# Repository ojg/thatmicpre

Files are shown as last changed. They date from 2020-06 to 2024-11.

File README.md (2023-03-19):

ThatMicPre
=====
A simple, high-quality DIY microphone pre-amplifier with switched gain.

The background for this project was that I needed a simple but good microphone preamp for doing acoustic measurements. I needed a switched gain to be able to reproduce the gain setting in a more predictable way than what is possible with a potmeter. I could not find any existing DIY designs, so I decided to make one.

The design is based on the excellent [THAT1510 or THAT1512](https://thatcorp.com/that-1510-1512-low-noise-high-performance-audio-preamplifiers/) preamp ICs. It is also compatible with [SSM2019](https://www.analog.com/en/products/ssm2019.html) or [INA217](https://www.ti.com/product/INA217). I have followed all THAT's datasheets and app-notes to implement a robust, best-practice design.

A goal was to use simple through-hole parts that I and other DIYers usually have in our parts drawer. So there are no additional IC's or voltage regulators for example, it just uses simple transistors, capacitors and zener diodes for supply filtering and regulation. I selected affordable switches and connectors to keep cost down. Many parts can be substituted without sacrificing performance.

There are two versions of this design, one suited for a desktop encolsure with gain switch on top, and one suited for a rack-mount enclosure with gain switch on the front.

There is a separate PCB project in the panels folder that contains PCB layout for front and back panels that fits the 1455K120x case. Since it is copper-clad on the inside, it makes for a nice shielded box.

This is an open-source project released under CC-BY-SA-4.0 license. It basically means you can use it as you want as long as you share modifications under the same license, and attribute back to this project. See [LICENSE.txt](../blob/master/LICENSE.txt) for details.

See discussion of this project in this [DIYAudio thread.](https://www.diyaudio.com/forums/equipment-and-tools/356317-thatmicpre-source-mic-preamp.html) If you decide to build this pre-amplifier, please post results of your build there.

Specifications
-----
* Microphone preamplifier with switched gain and 48V phantom power.
* XLR input and output connectors.
* Phantom power on/off switch.
* Phase invert switch.
* Gains (dB): 0, 10, 15, 20, 25, 30, 35, 40, 45, 50, 55, 60.
* Gain deviation from nominal: Max +/-0.5dB using R12-series resistors.
* Frequency response: 0/-3dB from 10Hz to 100kHz for all gain settings.
* Input impedance: 2.0kohm differential (1kHz)
* Impedance balanced output, output impedance 200ohm (1kHz)
* Max output level: 20dBu at 0.1% THD (1kHz).
* THD+N less than 0.005% at 1kHz at 18dBu output level for all gain settings (20-20kHz BW).
* 48V DC power supply required, 30mA max. 
  * (Will operate with lower voltage DC power supplies with reduced phantom voltage and max output level).
* PCB dimensions 75mm x 120mm, fits the [Hammond 1455K120x](https://www.hammfg.com/part/1455K1201) enclosure.
  * Desktop version has gain switch on top of enclosure for easy access.
  * Rack version has gain switch on front for easy mounting in a rack enclosure.

Photos
-----
#### Desktop version
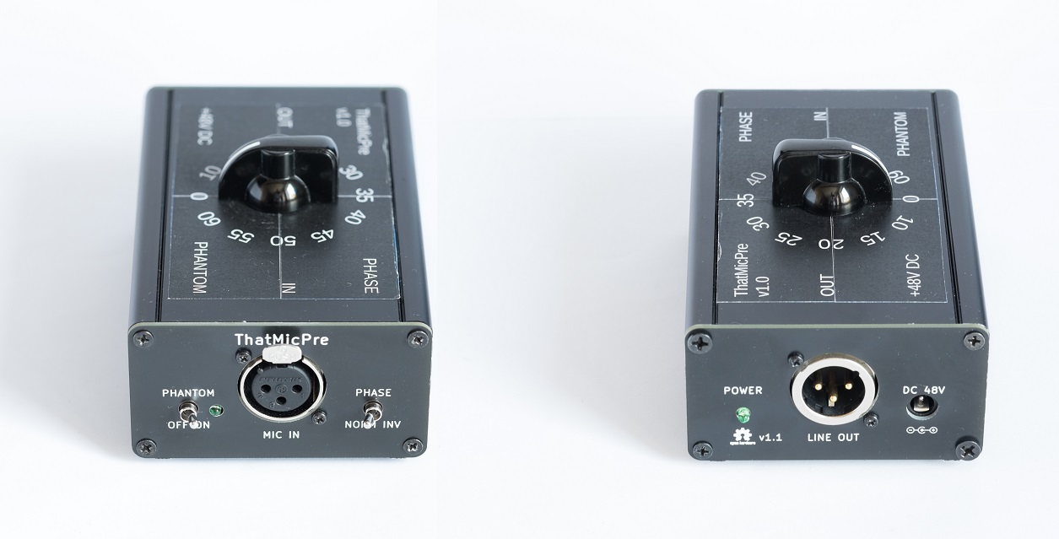
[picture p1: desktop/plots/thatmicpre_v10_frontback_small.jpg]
Photo of desktop Desktop with panels


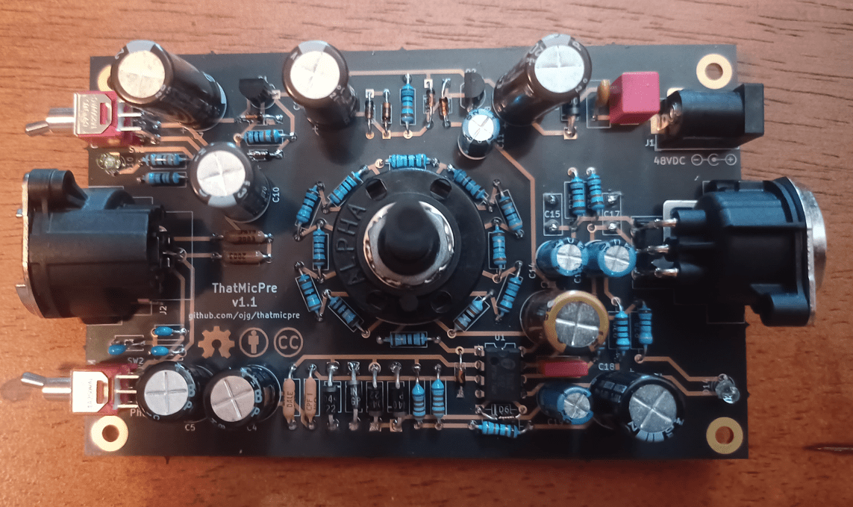
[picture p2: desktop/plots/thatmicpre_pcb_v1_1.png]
Photo of desktop pcb Desktop PCB photo

(PCBA credit jsenderatx on diyaudio)

#### Rack version
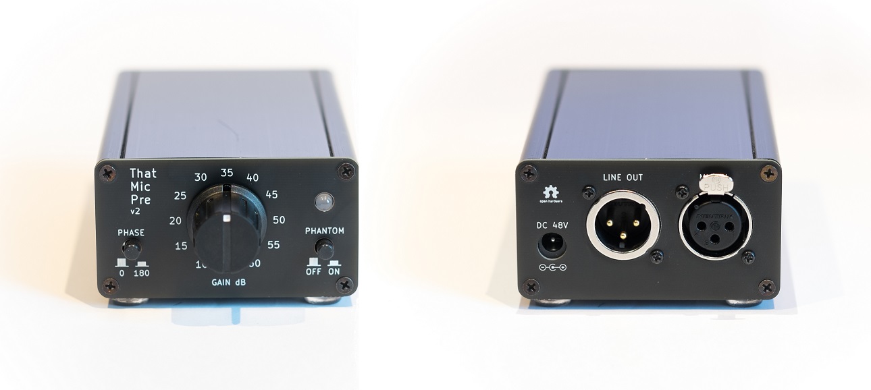
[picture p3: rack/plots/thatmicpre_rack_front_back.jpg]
Photo of rack Rack with panels


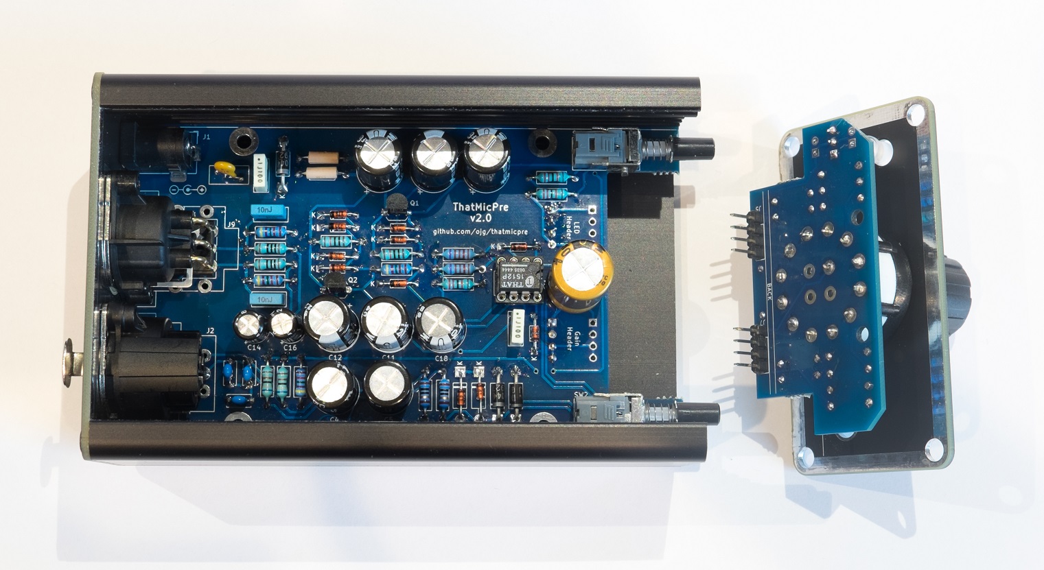
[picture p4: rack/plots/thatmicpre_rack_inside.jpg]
Photo of rack pcb Rack PCB photo


The rack version has a PCB where one part separates. This part contains the gain resistors and switch.
It mounts at a right angle to the main PCB with two angled female headers underneath main PCB. See BOM.

## Bill of Materials
Nicely formatted BOM is in the plots folder for [desktop version](https://htmlpreview.github.io/?https://github.com/ojg/thatmicpre/blob/master/desktop/plots/thatmicpre_bom.html)
and [rack version](https://htmlpreview.github.io/?https://github.com/ojg/thatmicpre/blob/master/rack/plots/thatmicpre_v2_bom.html).

Thanks to the [InteractiveHtmlBom project](https://github.com/openscopeproject/InteractiveHtmlBom).

Schematic
-----
#### Desktop version
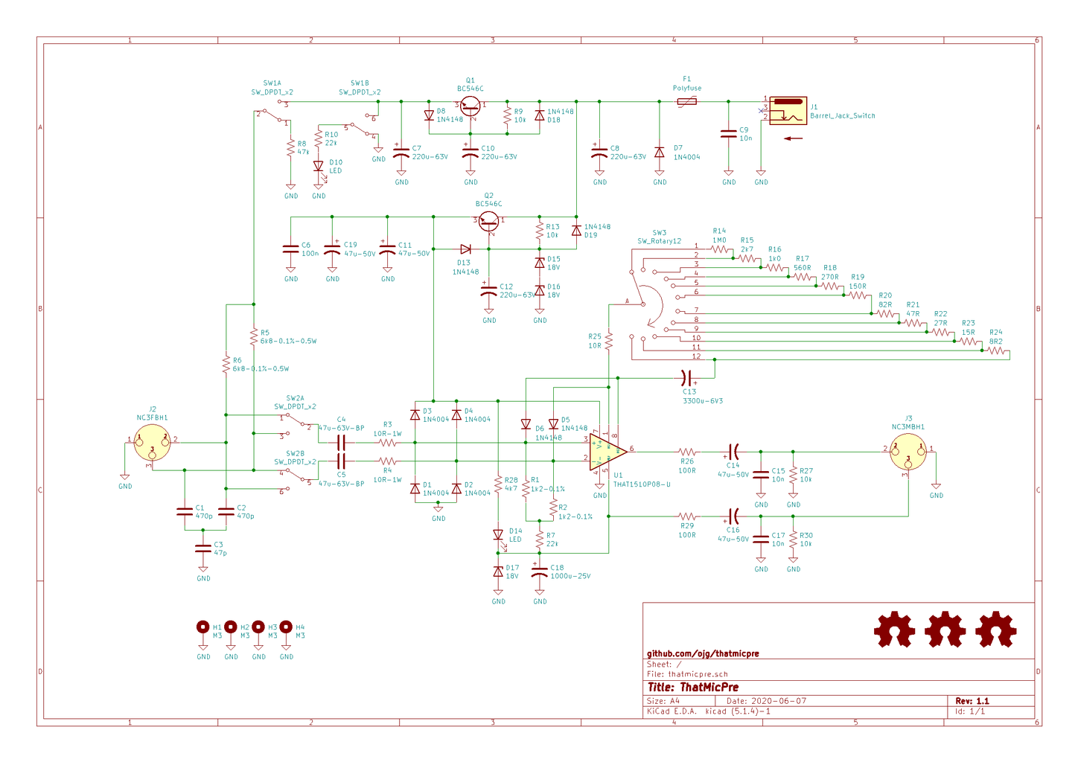
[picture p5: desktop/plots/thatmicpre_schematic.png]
Schematic

#### Rack version
Schematic

Measurements
-----
### Output noise vs gain
20-22kHz BW un-wtd, 150ohm source impedance.
Note: Theoretical minimum EIN with 150ohm source impedance is -130.4dBu.

| Gain(dB) | THAT1510<br />Output Noise (dBu) | THAT1510<br />EIN (dBu) | THAT1512<br />Output Noise (dBu) | THAT1512<br />EIN (dBu) |
| --- | --- | --- |--- | --- |
| 0 | -98.5 | -98.5 | -102.4 | -102.4 |
| 10 | -98.2 | -108.2 | -102.0 | -112.0 |
| 15 | -97.8 | -112.8 | -101.3 | -116.3 |
| 20 | -96.8 | -116.8 | -100.0 | -120.0 |
| 25 | -95.6 | -120.6 | -98.0 | -123.0 |
| 30 | -93.2 | -123.2 | -95.2 | -125.2 |
| 35 | -89.8 | -124.8 | -91.5 | -126.5 |
| 40 | -86.8 | -126.8 | -87.3 | -127.3 |
| 45 | -82.6 | -127.6 | -82.8 | -127.8 |
| 50 | -77.8 | -127.8 | -78.1 | -128.1 |
| 55 | -73.1 | -128.1 | -73.3 | -128.3 |
| 60 | -68.3 | -128.3 | -68.6 | -128.6 |

### Frequency Response
#### THAT1510 with 1% R12 resistors
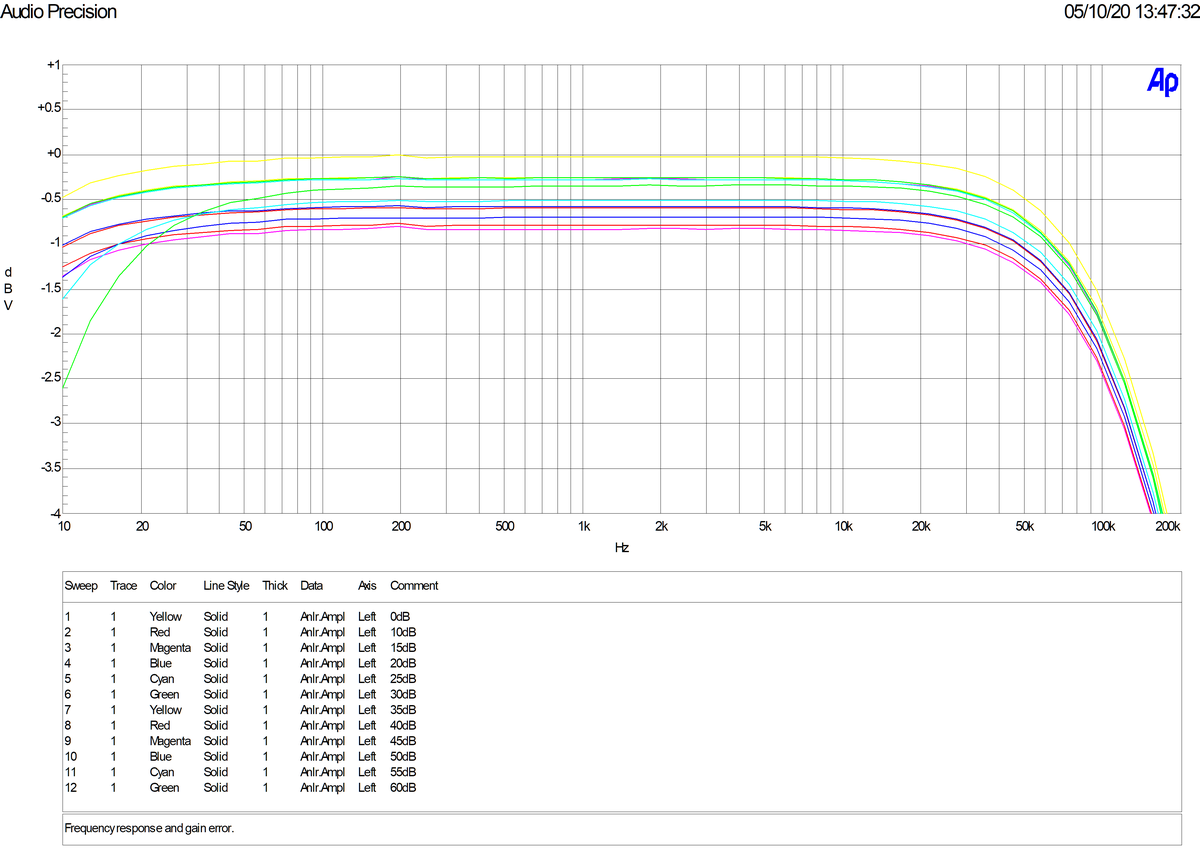
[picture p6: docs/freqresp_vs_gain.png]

#### THAT1512 with 1% R96 resistors
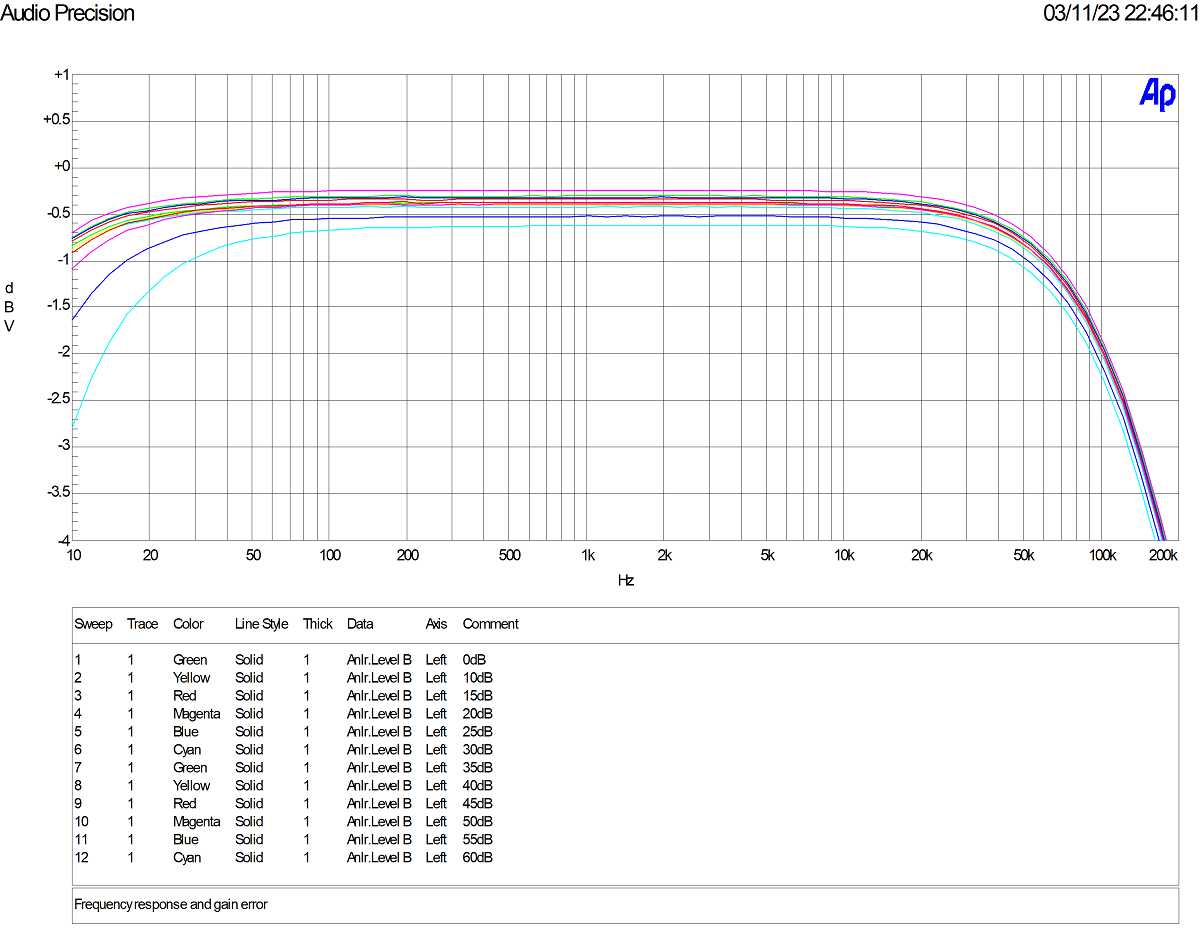
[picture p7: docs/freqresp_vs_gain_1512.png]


### THD+N vs Frequency
#### THAT1510
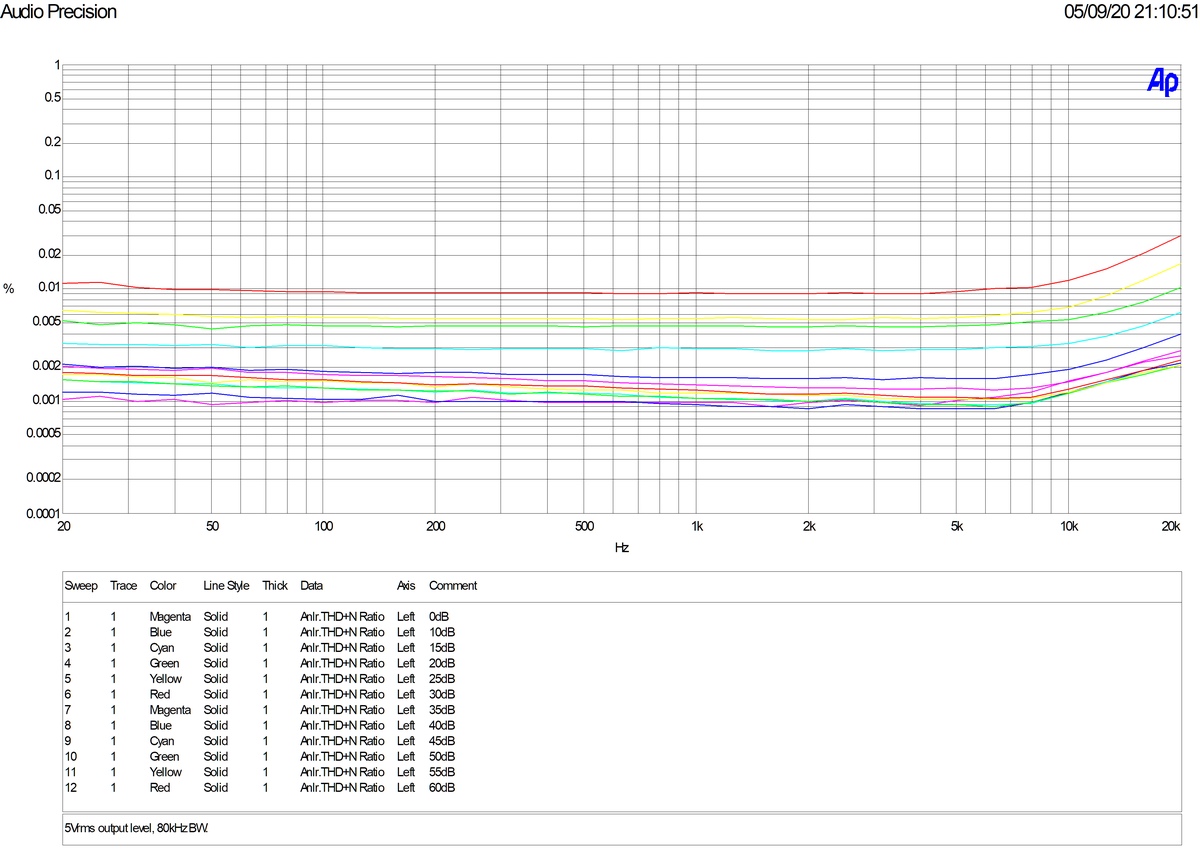
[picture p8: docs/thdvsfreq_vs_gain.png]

#### THAT1512
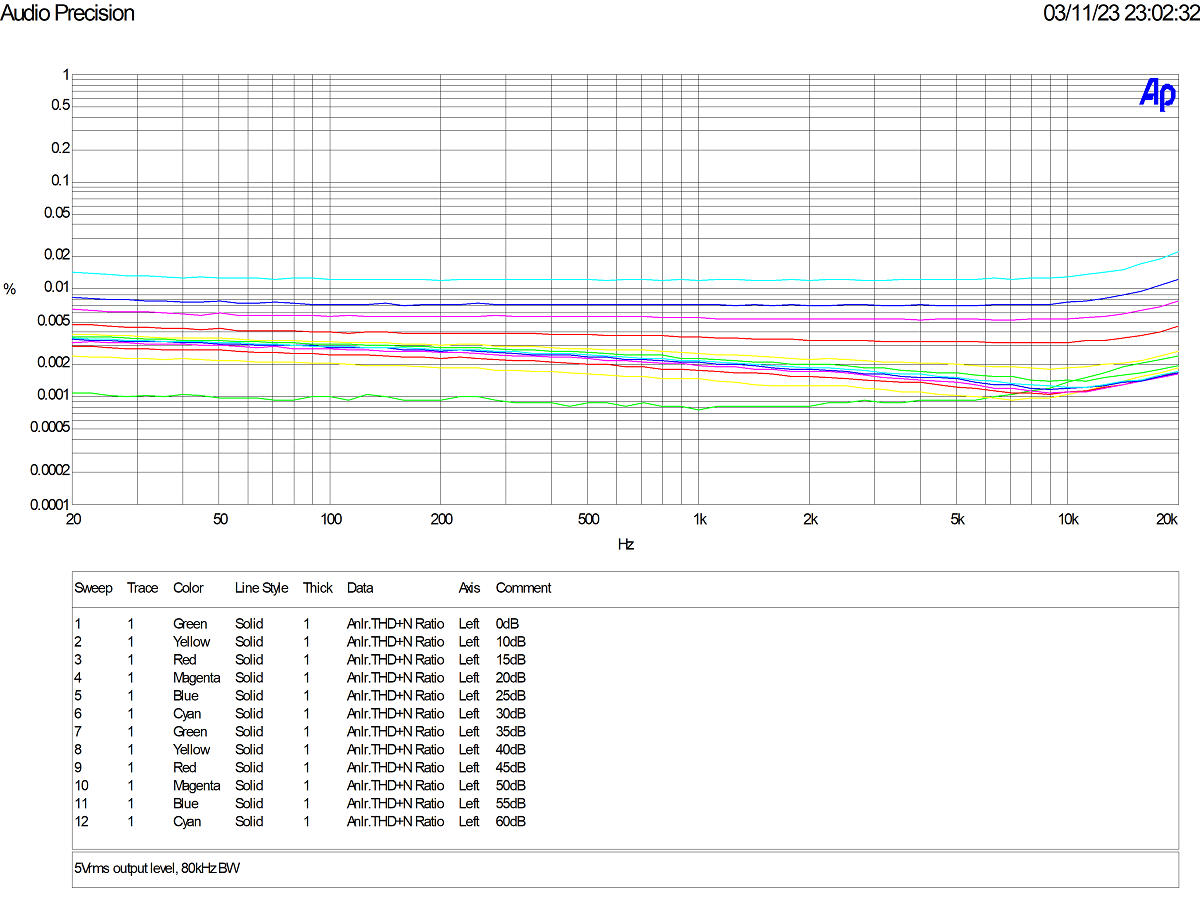
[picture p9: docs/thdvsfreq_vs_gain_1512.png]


### THD+N vs Amplitude
#### THAT1510
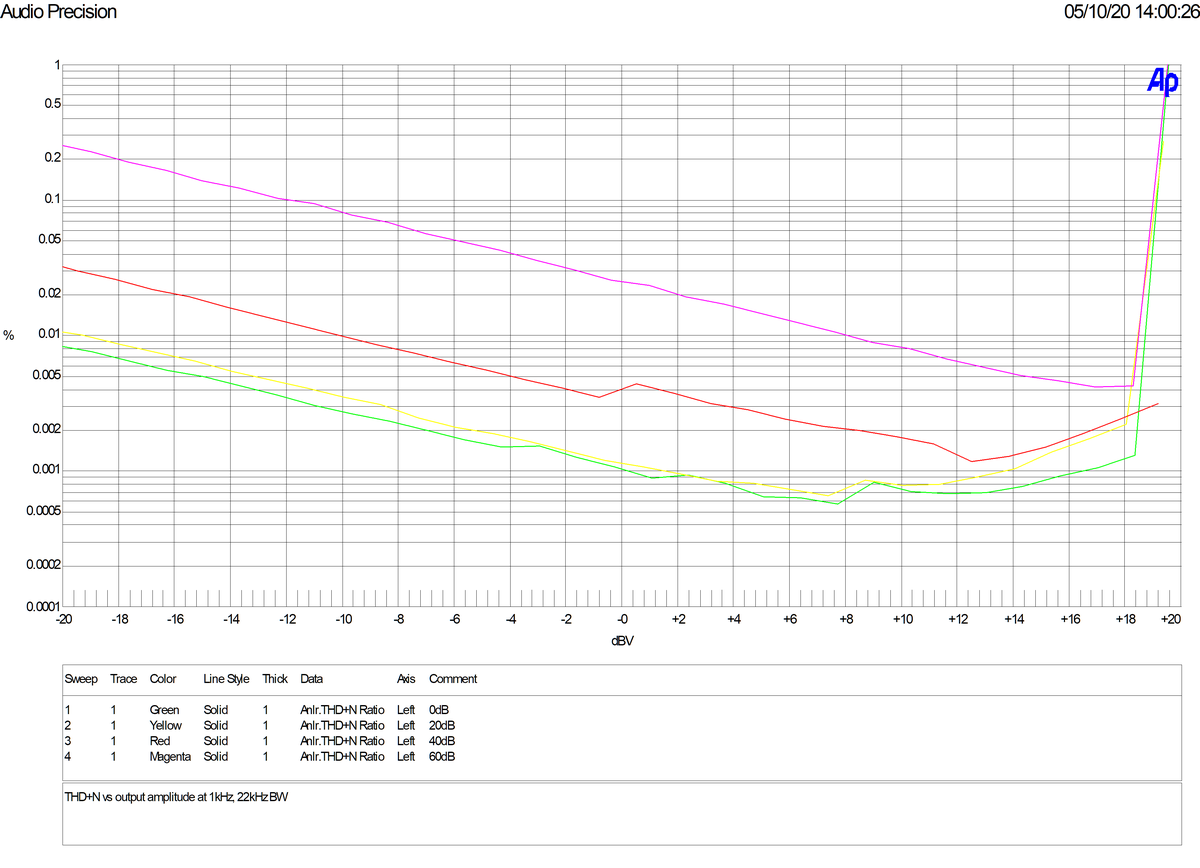
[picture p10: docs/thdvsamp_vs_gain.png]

#### THAT1512
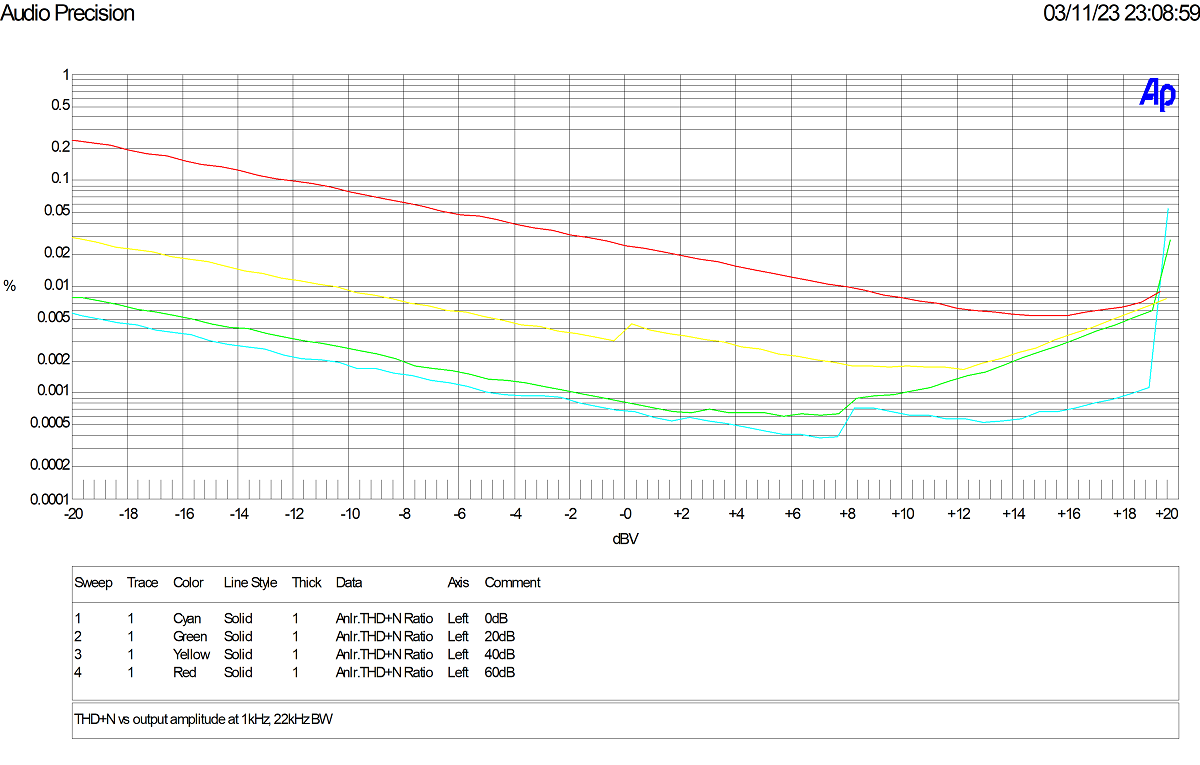
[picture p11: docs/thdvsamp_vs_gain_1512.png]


### Common Mode Rejection Ratio
#### THAT1510
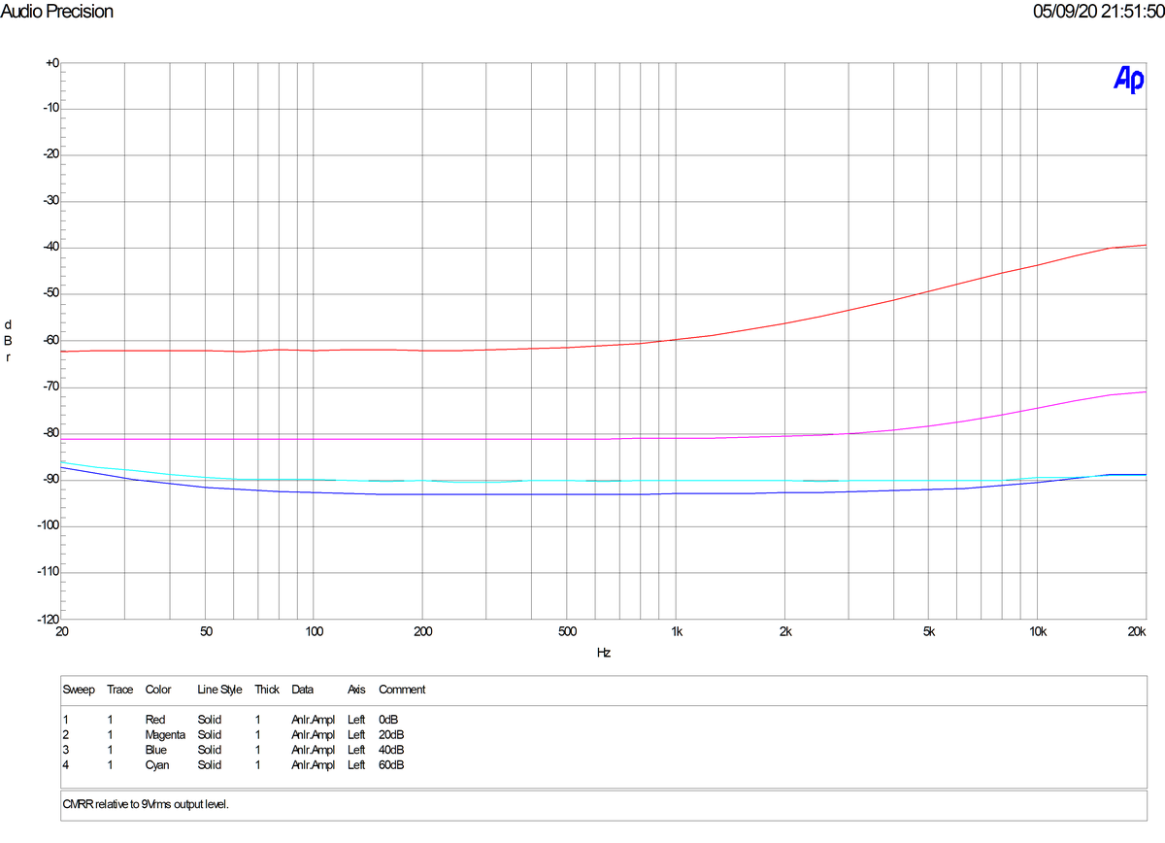
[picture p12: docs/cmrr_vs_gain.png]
CMRR

#### THAT1512
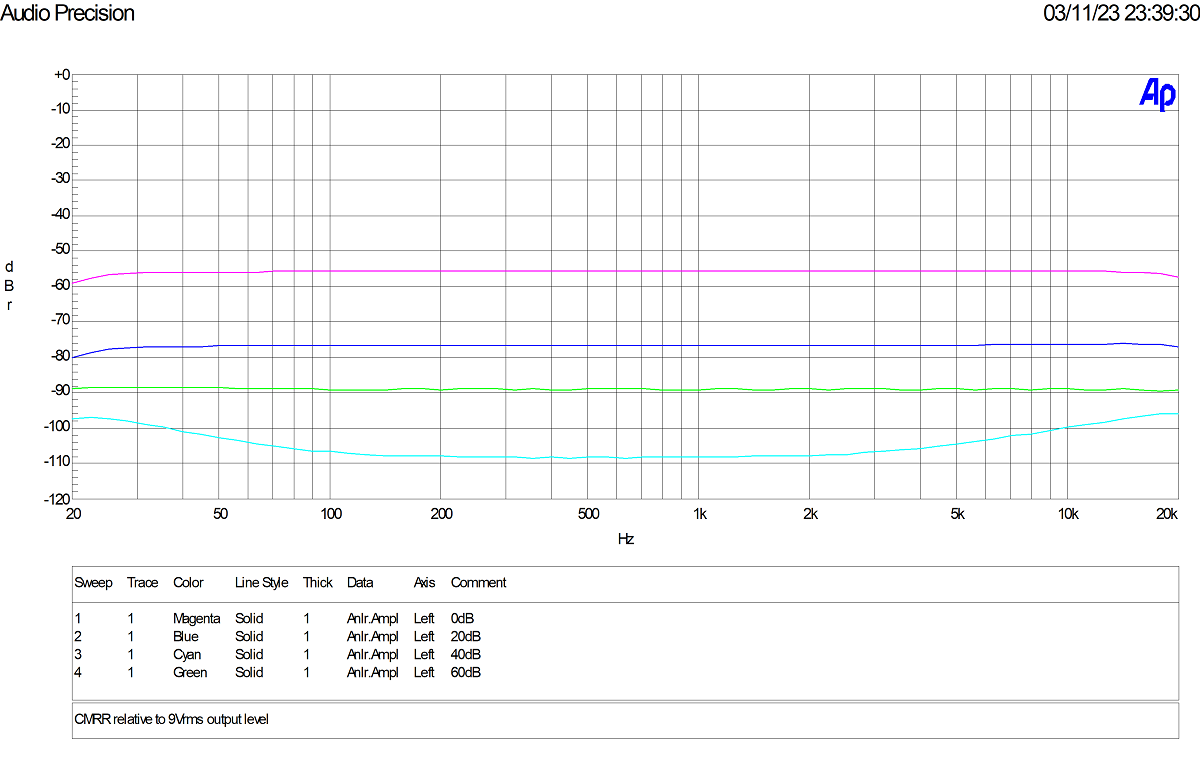
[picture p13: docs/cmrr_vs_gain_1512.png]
CMRR


### Bandpass Noise Level
Note no measureable hum.
#### THAT1510
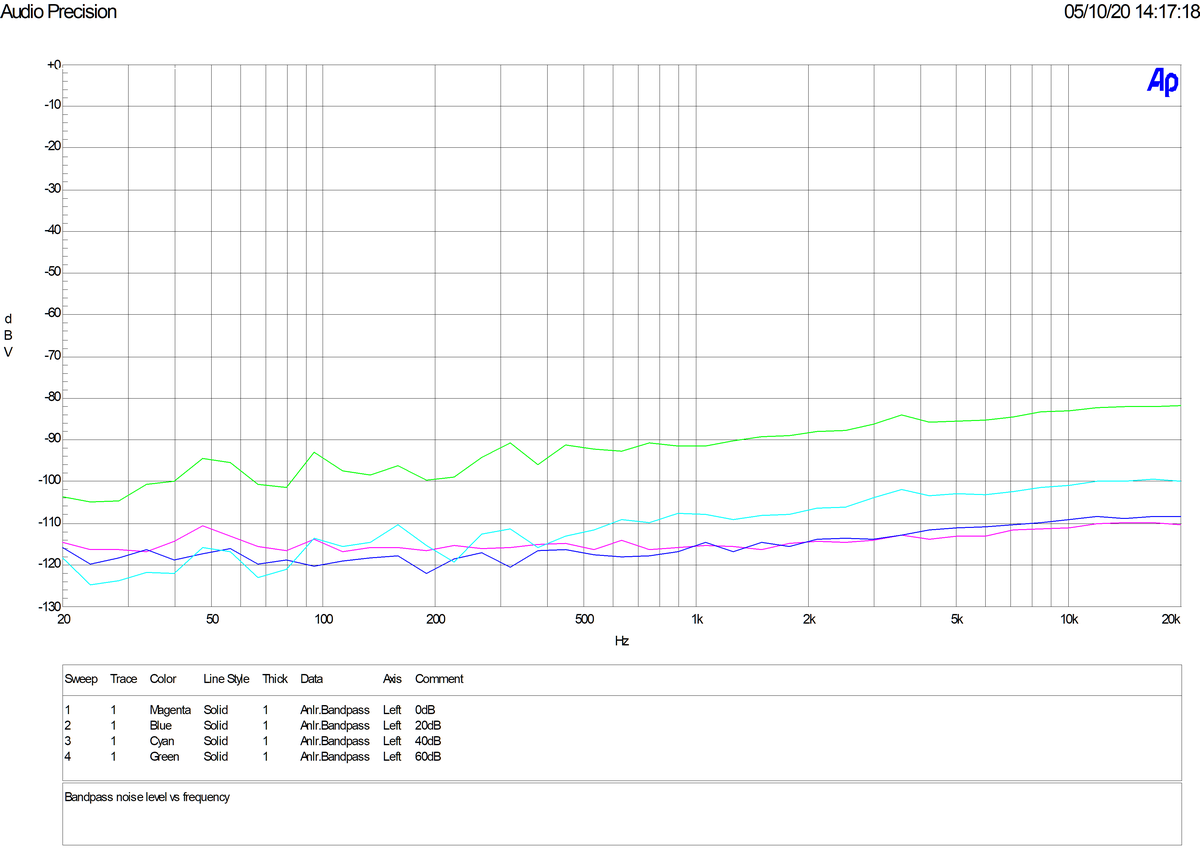
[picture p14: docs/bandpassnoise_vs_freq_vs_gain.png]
Bandpass

#### THAT1512
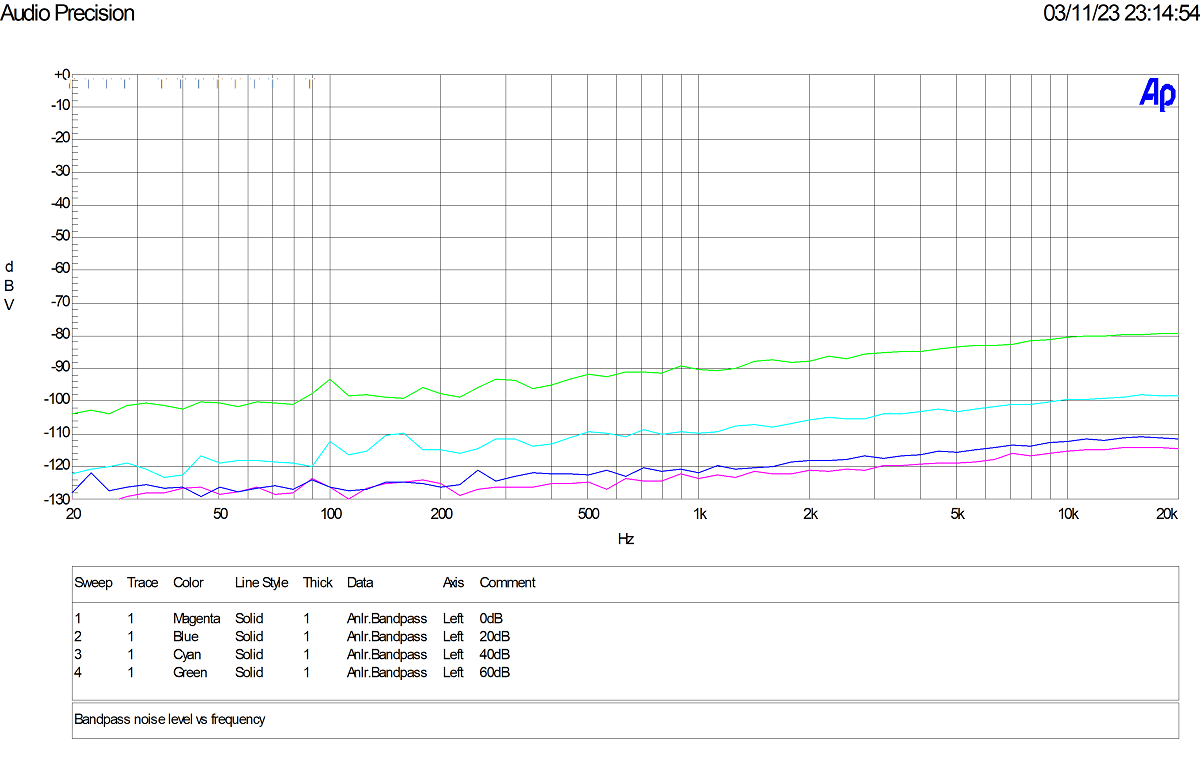
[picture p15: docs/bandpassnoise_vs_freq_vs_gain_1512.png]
Bandpass


---
OJG 2023

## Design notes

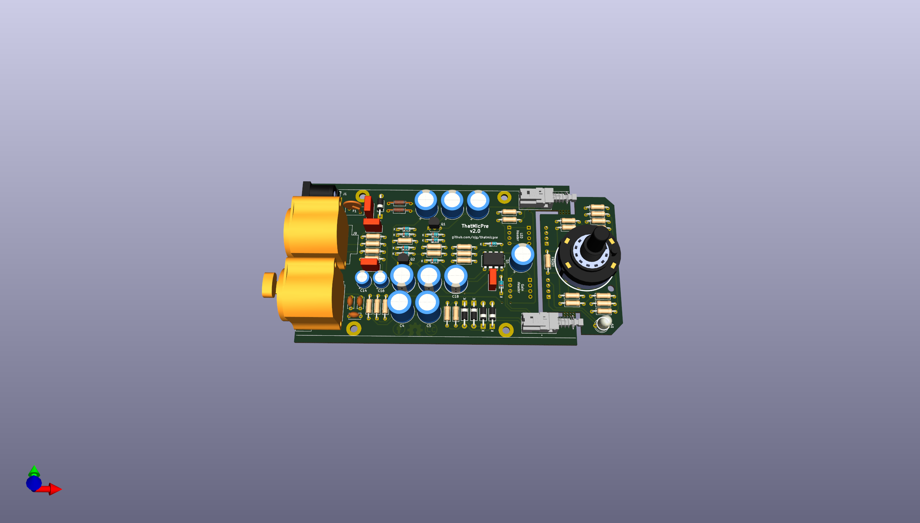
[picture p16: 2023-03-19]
rack/plots/thatmicpre_v2_3drender.png

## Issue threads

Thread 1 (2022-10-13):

input impedance problem

SJetandKara, 2022-10-13:
what is the input impedance of this preamp？
maybe by tweaking the input impedance we can get different sound features like ISA preamp(which provided input impedance options like 600Ω/1100Ω/2.4kΩ/6.8kΩ)？

ojg, 2022-10-16:
The input impedance with the values shown in the schematic is ~2kohm differentially.

It's (R5+R6) || (R1+R2). So you can tune it easily by changing R1 and R2.

Closed 2024-02-11.

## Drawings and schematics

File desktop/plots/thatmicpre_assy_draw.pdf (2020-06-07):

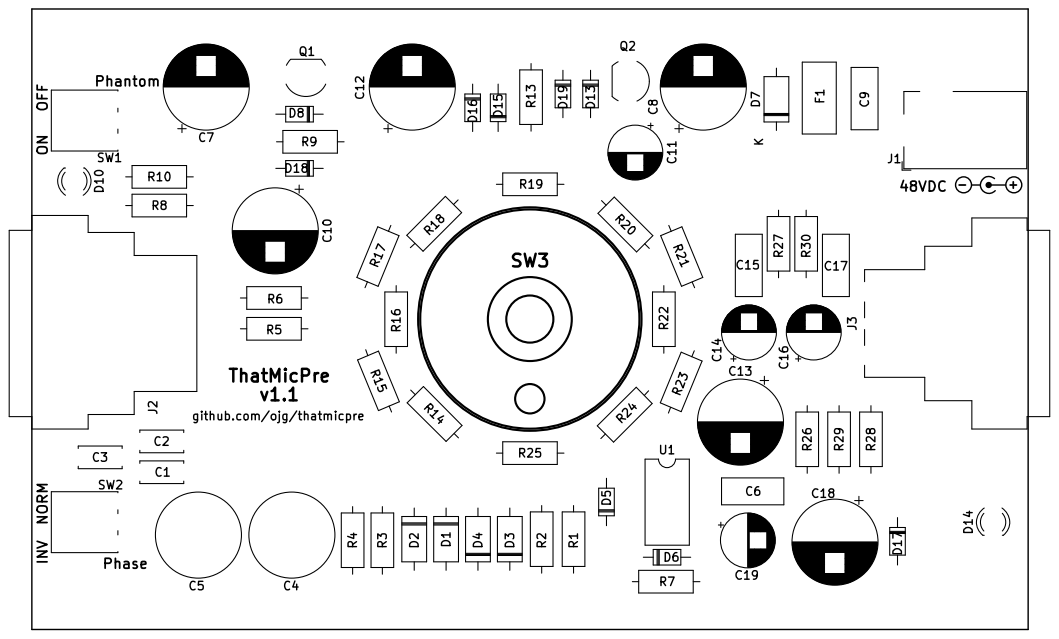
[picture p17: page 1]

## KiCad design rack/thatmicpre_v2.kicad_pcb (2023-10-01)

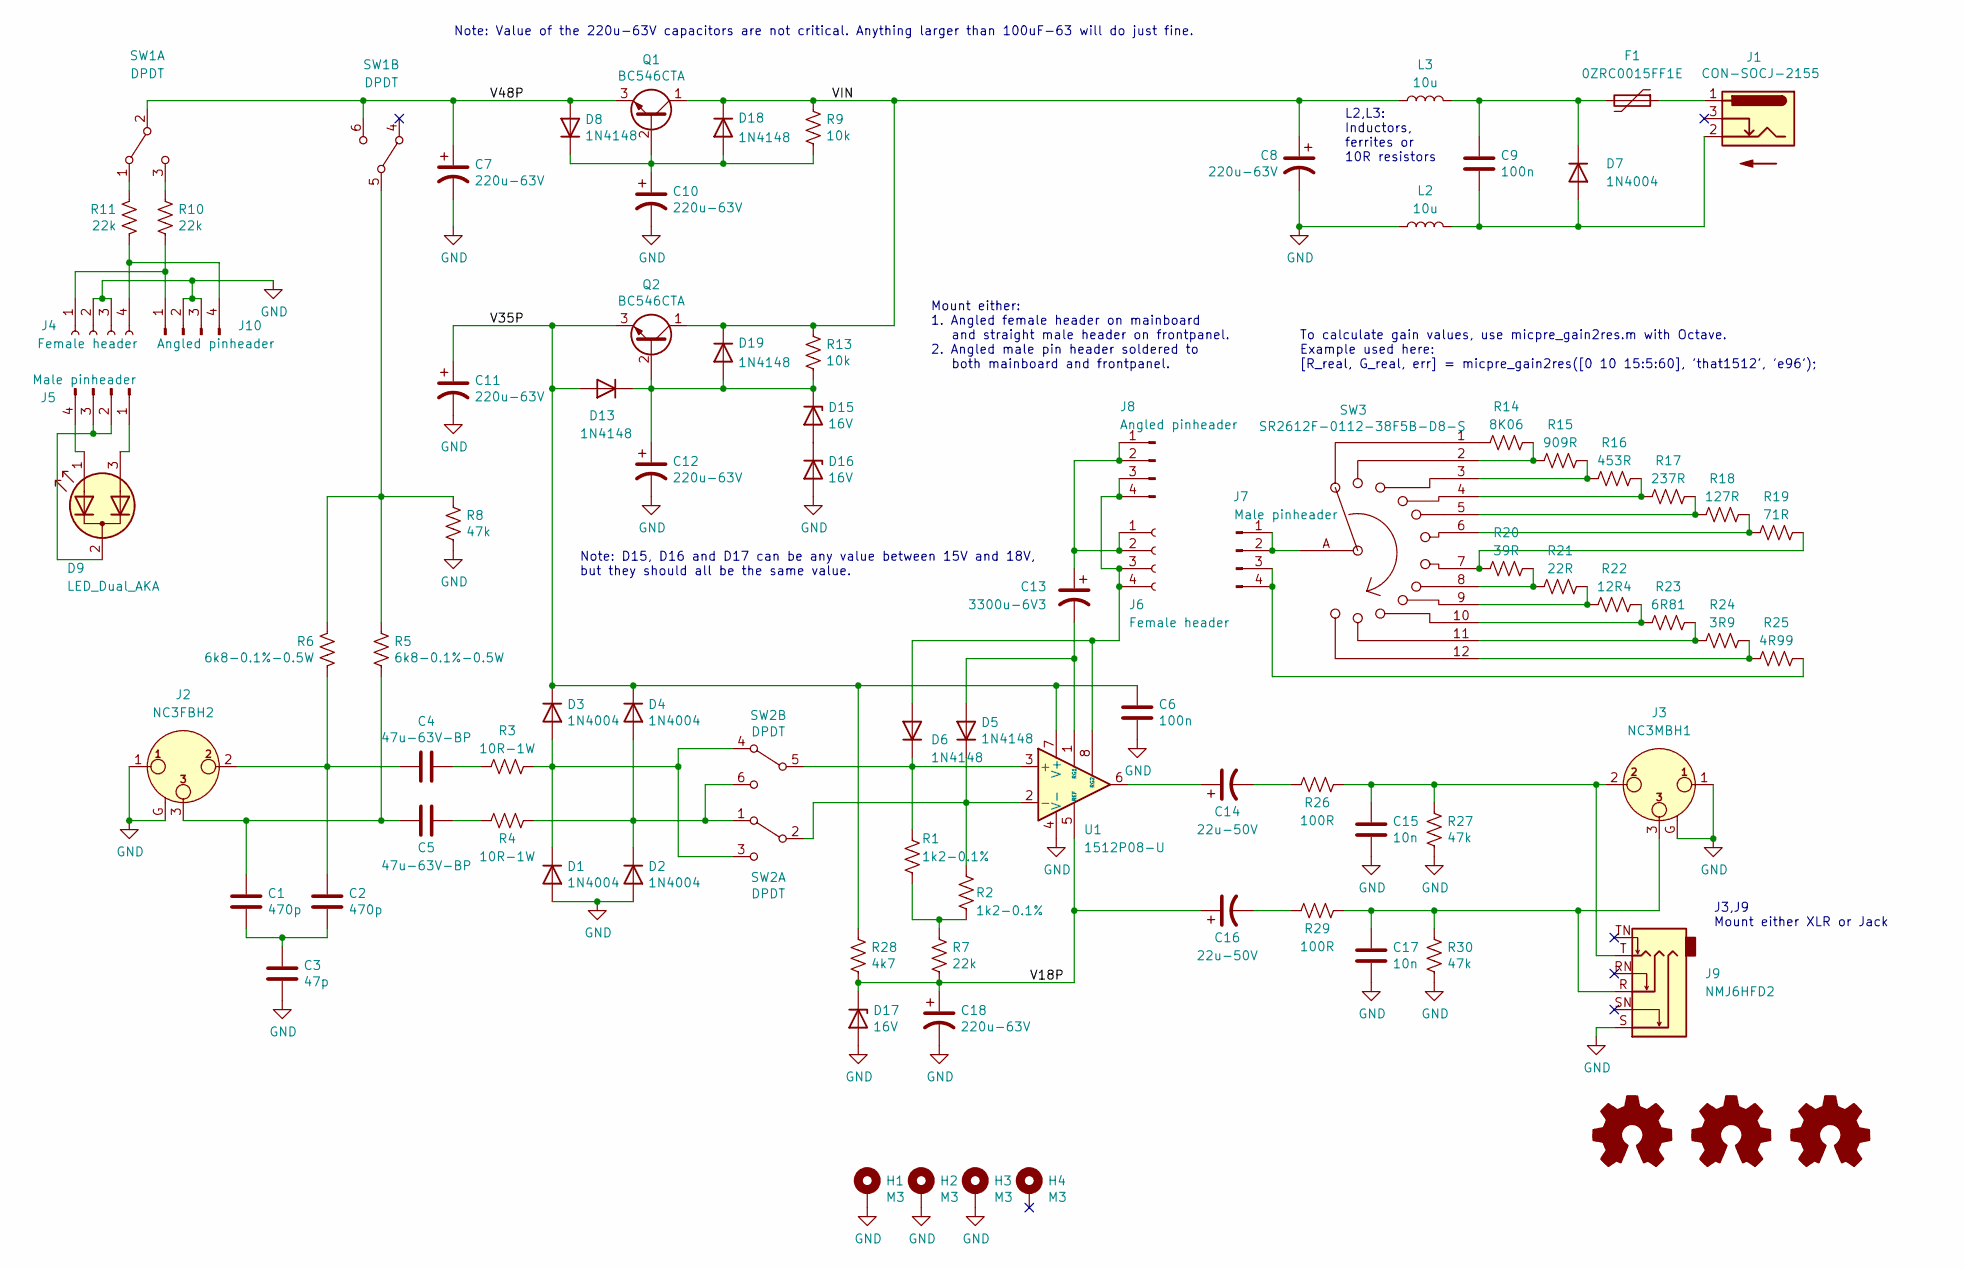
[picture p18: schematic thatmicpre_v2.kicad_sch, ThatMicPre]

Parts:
C1, C2: 470p; C_Disc_D5.0mm_W2.5mm_P5.00mm; Mfr Part Nr FG28C0G2A471JNT0
C3: 47p; C_Disc_D5.0mm_W2.5mm_P5.00mm; Mfr Part Nr FG28C0G2A470JNT0
C4, C5: 47u-63V-BP; C_Radial_D10.0mm_H16.0mm_P5.00mm; Mfr Part Nr UVP1J470MPD
C6, C9: 100n; C_Rect_L7.2mm_W3.0mm_P5.00mm_FKS2_FKP2_MKS2_MKP2; Mfr Part Nr R82EC3100AA70J
C7, C8, C10, C11, C12, C18: 220u-63V; CP_Radial_D10.0mm_P5.00mm; Mfr Part Nr UPW1J221MPD
C13: 3300u-6V3; CP_Radial_D10.0mm_P5.00mm; Mfr Part Nr UFW0J332MPD
C14, C16: 22u-50V; CP_Radial_D6.3mm_P2.50mm; Mfr Part Nr UEP1V220MED
C15, C17: 10n; C_Rect_L7.2mm_W3.0mm_P5.00mm_FKS2_FKP2_MKS2_MKP2; Mfr Part Nr PHE426DJ5100JR05
D1, D2, D3, D4, D7: 1N4004; D_DO-41_SOD81_P10.16mm_Horizontal; Mfr Part Nr 1N4004GP
D5, D6, D8, D13, D18, D19: 1N4148; D_DO-34_SOD68_P7.62mm_Horizontal; Mfr Part Nr 1N4148
D9: LED_Dual_AKA; LED_D5.0mm-3; Mfr Part Nr WP59EGW
D15, D16, D17: 16V; D_DO-34_SOD68_P7.62mm_Horizontal; Mfr Part Nr BZX55B16
F1: 0ZRC0015FF1E; Fuse_BelFuse_0ZRE0005FF_L8.3mm_W3.8mm; Mfr Part Nr 0ZRC0015FF1E
H1, H2, H3, H4: M3; MountingHole_3.2mm_M3_Pad
J1: CON-SOCJ-2155; BarrelJack_Horizontal; Mfr Part Nr CON-SOCJ-2155
J2: NC3FBH2; Jack_XLR_Neutrik_NC3FBH2_Horizontal; Mfr Part Nr NC3FBH2
J3: NC3MBH1; Jack_XLR_Neutrik_NC3MBH_Horizontal; Mfr Part Nr NC3MBH1
J4, J6: Female header; PinSocket_1x04_P2.54mm_Horizontal; Mfr Part Nr SSQ-104-02-T-S-RA
J5, J7: Male pinheader; PinHeader_1x04_P2.54mm_Vertical; Mfr Part Nr TSW-104-07-T-S
J8, J10: Angled pinheader; PinHeader_1x04_P2.54mm_Vertical; Mfr Part Nr TSW-104-08-F-S-RA
J9: NMJ6HFD2; Jack_6.35mm_Neutrik_NMJ6HFD2_Horizontal; Mfr Part Nr NMJ6HFD2
L2, L3: 10u; L_Axial_L5.3mm_D2.2mm_P10.16mm_Horizontal_Vishay_IM-1; Mfr Part Nr 78F100J-TR-RC
LOGO1: Logo_Open_Hardware_Small; OSHW-Symbol_6.7x6mm_Copper
LOGO2: Logo_Open_Hardware_Small; Symbol_CC-Attribution_CopperTop_Small
LOGO3: Logo_Open_Hardware_Small; Symbol_CreativeCommons_CopperTop_Type2_Small
LOGO4: SYM_Arrow_Normal; Symbol_Barrel_Polarity
Q1, Q2: BC546CTA; TO-92_Inline_Wide; Mfr Part Nr BC546CTA
R1, R2: 1k2-0.1%; R_Axial_DIN0207_L6.3mm_D2.5mm_P10.16mm_Horizontal; Mfr Part Nr YR1B1K21CC
R3, R4: 10R-1W; R_Axial_DIN0207_L6.3mm_D2.5mm_P10.16mm_Horizontal; Mfr Part Nr CPF110R000FEB14
R5, R6: 6k8-0.1%-0.5W; R_Axial_DIN0207_L6.3mm_D2.5mm_P10.16mm_Horizontal; Mfr Part Nr CMF556K8100BEEK
R7, R10, R11: 22k; R_Axial_DIN0207_L6.3mm_D2.5mm_P10.16mm_Horizontal; Mfr Part Nr MBB02070C2202FCT00
R8, R27, R30: 47k; R_Axial_DIN0207_L6.3mm_D2.5mm_P10.16mm_Horizontal; Mfr Part Nr MBB02070C4702FCT00
R9, R13: 10k; R_Axial_DIN0207_L6.3mm_D2.5mm_P10.16mm_Horizontal; Mfr Part Nr MBB02070C1002FCT00
R14: 8K06; R_Axial_DIN0207_L6.3mm_D2.5mm_P10.16mm_Horizontal; Mfr Part Nr MFR50SFTE52-8K06
R15: 909R; R_Axial_DIN0207_L6.3mm_D2.5mm_P10.16mm_Horizontal; Mfr Part Nr MFR50SFTE52-909R
R16: 453R; R_Axial_DIN0207_L6.3mm_D2.5mm_P10.16mm_Horizontal; Mfr Part Nr MFR50SFTE52-453R
R17: 237R; R_Axial_DIN0207_L6.3mm_D2.5mm_P10.16mm_Horizontal; Mfr Part Nr MFR50SFTE52-237R
R18: 127R; R_Axial_DIN0207_L6.3mm_D2.5mm_P10.16mm_Horizontal; Mfr Part Nr MFR50SFTE52-127R
R19: 71R; R_Axial_DIN0207_L6.3mm_D2.5mm_P10.16mm_Horizontal; Mfr Part Nr MFR50SFTE52-71R
R20: 39R; R_Axial_DIN0207_L6.3mm_D2.5mm_P10.16mm_Horizontal; Mfr Part Nr MFR50SFTE52-39R
R21: 22R; R_Axial_DIN0207_L6.3mm_D2.5mm_P10.16mm_Horizontal; Mfr Part Nr MFR50SFTE52-22R
R22: 12R4; R_Axial_DIN0207_L6.3mm_D2.5mm_P10.16mm_Horizontal; Mfr Part Nr MFR50SFTE52-12R4
R23: 6R81; R_Axial_DIN0207_L6.3mm_D2.5mm_P10.16mm_Horizontal; Mfr Part Nr MFR50SFTE52-6R81
R24: 3R9; R_Axial_DIN0207_L6.3mm_D2.5mm_P10.16mm_Horizontal; Mfr Part Nr MFR50SFTE52-3R9
R25: 4R99; R_Axial_DIN0207_L6.3mm_D2.5mm_P10.16mm_Horizontal; Mfr Part Nr MFR50SFTE52-4R99
R26, R29: 100R; R_Axial_DIN0207_L6.3mm_D2.5mm_P10.16mm_Horizontal; Mfr Part Nr MFR50SFTE52-100R
R28: 4k7; R_Axial_DIN0207_L6.3mm_D2.5mm_P10.16mm_Horizontal; Mfr Part Nr MBB02070C4701FCT00
SW1, SW2: DPDT; SW_PBH2UEESNPNAGX; Mfr Part Nr PBH2UEESNPNAGX
SW3: SR2612F-0112-38F5B-D8-S; LORINCK1049; Mfr Part Nr SR2612F-0112
U1: 1512P08-U; DIP-8_W7.62mm; Mfr Part Nr 1512P08-U

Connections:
/V18P: C16.1, C18.1, D17.1 (K), R7.2, R28.2, U1.5 (REF)
/V35P: C6.1, C11.1, D3.1 (K), D4.1 (K), D13.2 (A), Q2.3 (E), R28.1, U1.7 (V+)
/V48P: C7.1, D8.2 (A), Q1.3 (E), SW1.2 (B), SW1.6 (C)
/VIN: C8.1, D18.1 (K), D19.1 (K), L3.1, Q1.1 (C), Q2.1 (C), R9.1, R13.1
GND: C3.2, C6.2, C7.2, C8.2, C10.2, C11.2, C12.2, C15.2, C17.2, C18.2, D1.2 (A), D2.2 (A), D16.2 (A), D17.2 (A), H1.1, H2.1, H3.1, J2.1, J2.G, J3.1, J3.G, J4.2, J4.3, J9.S, J10.2, J10.3, L2.1, R8.2, R27.2, R30.2, U1.4 (V-)
unnamed: C1.1, C5.1, J2.3, R5.2
unnamed: C1.2, C2.2, C3.1
unnamed: C2.1, C4.1, J2.2, R6.2
unnamed: C4.2, R3.2
unnamed: C5.2, R4.2
unnamed: C9.1, D7.1 (K), F1.2, L3.2
unnamed: C9.2, D7.2 (A), J1.2, L2.2
unnamed: C10.1, D8.1 (K), D18.2 (A), Q1.2 (B), R9.2
unnamed: C12.1, D13.1 (K), D15.1 (K), D19.2 (A), Q2.2 (B), R13.2
unnamed: C13.1, J6.1, J6.2, J8.1, J8.2
unnamed: C13.2, D5.2 (A), U1.1 (RG1)
unnamed: C14.1, U1.6
unnamed: C14.2, R26.2
unnamed: C15.1, J3.2, J9.T, R26.1, R27.1
unnamed: C16.2, R29.2
unnamed: C17.1, J3.3, J9.R, R29.1, R30.1
unnamed: D1.1 (K), D3.2 (A), R3.1, SW2.3 (C), SW2.4 (A)
unnamed: D2.1 (K), D4.2 (A), R4.1, SW2.1 (A), SW2.6 (C)
unnamed: D5.1 (K), R2.1, SW2.2 (B), U1.2 (-)
unnamed: D6.1 (K), R1.1, SW2.5 (B), U1.3 (+)
unnamed: D6.2 (A), J6.3, J6.4, J8.3, J8.4, U1.8 (RG2)
unnamed: D9.1 (A1), J5.4
unnamed: D9.2 (K), J5.2, J5.3
unnamed: D9.3 (A2), J5.1
unnamed: D15.2 (A), D16.1 (K)
unnamed: F1.1, J1.1
unnamed: J7.1, J7.2, SW3.A
unnamed: J7.3, J7.4, R25.2
unnamed: J4.1, J10.1, R10.2
unnamed: J4.4, J10.4, R11.2
unnamed: R1.2, R2.2, R7.1
unnamed: R5.1, R6.1, R8.1, SW1.5 (B)
unnamed: R10.1, SW1.3 (C)
unnamed: R11.1, SW1.1 (A)
unnamed: R14.1, R15.2, SW3.2
unnamed: R14.2, SW3.1
unnamed: R15.1, R16.2, SW3.3
unnamed: R16.1, R17.2, SW3.4
unnamed: R17.1, R18.2, SW3.5
unnamed: R18.1, R19.2, SW3.6
unnamed: R19.1, R20.2, SW3.7
unnamed: R20.1, R21.2, SW3.8
unnamed: R21.1, R22.2, SW3.9
unnamed: R22.1, R23.2, SW3.10
unnamed: R23.1, R24.2, SW3.11
unnamed: R24.1, R25.1, SW3.12

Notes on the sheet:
To calculate gain values, use micpre_gain2res.m with Octave. Example used here: [R_real, G_real, err] = micpre_gain2res([0 10 15:5:60], 'that1512', 'e96');
J3,J9 Mount either XLR or Jack
Mount either: 1. Angled female header on mainboard and straight male header on frontpanel. 2. Angled male pin header soldered to both mainboard and frontpanel.
L2,L3: Inductors, ferrites or 10R resistors
Note: Value of the 220u-63V capacitors are not critical. Anything larger than 100uF-63 will do just fine.
Note: D15, D16 and D17 can be any value between 15V and 18V, but they should all be the same value.

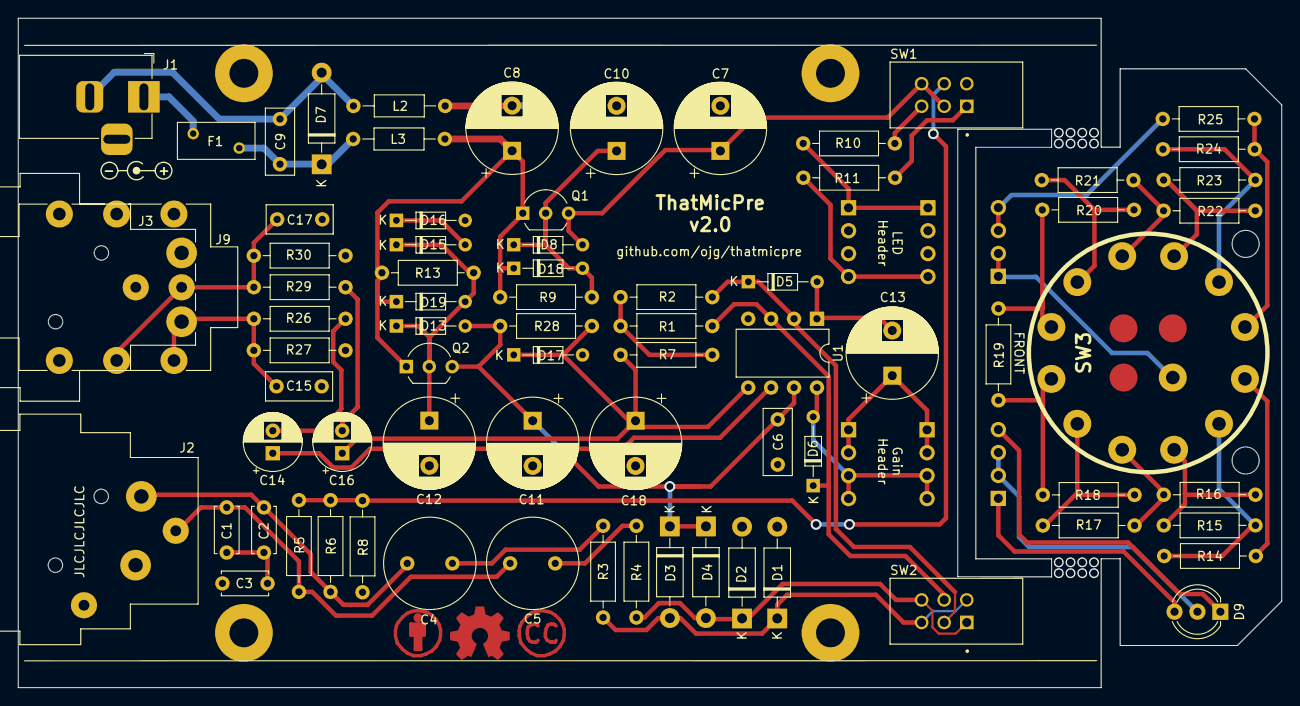
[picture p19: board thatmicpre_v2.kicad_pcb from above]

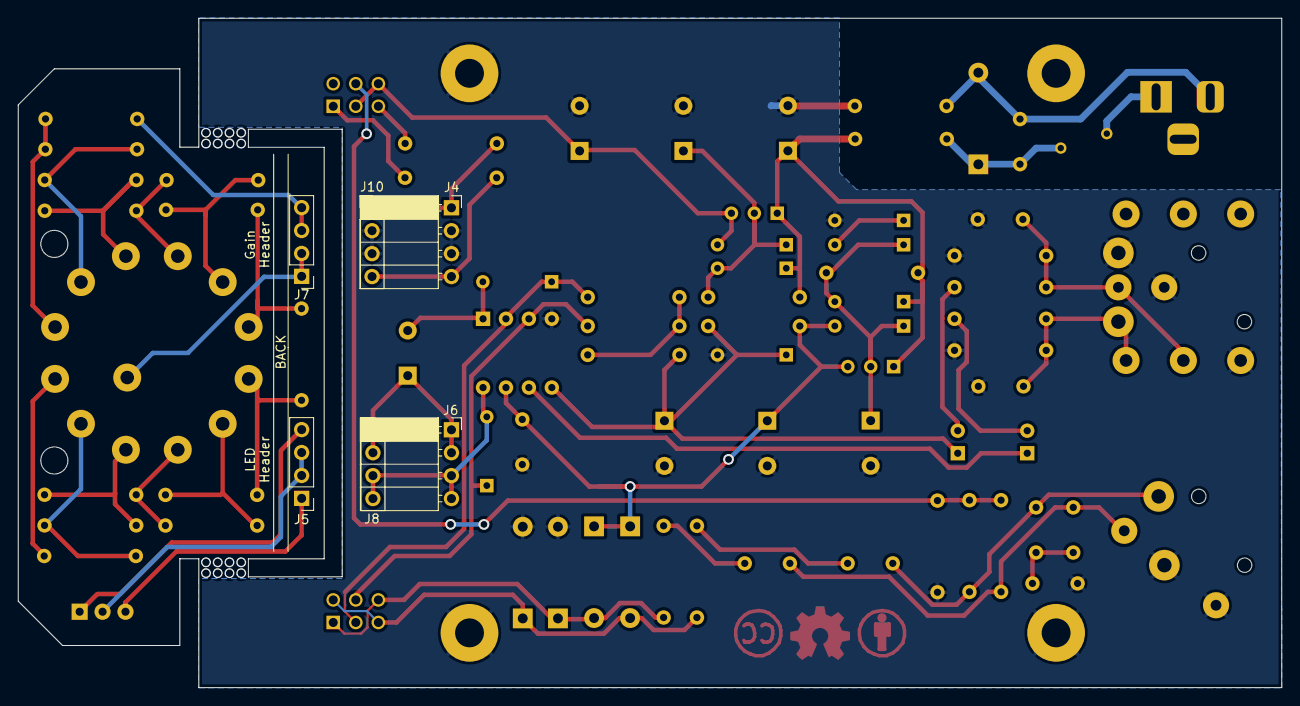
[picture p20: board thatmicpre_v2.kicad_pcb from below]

Board: 2 copper layers, 140.0 x 74.2 mm, 89 parts (6 on the bottom side), 51 nets.

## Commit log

2020-05-13 Add sch and pcb v1.0
    [thatmicpre.kicad_pcb, thatmicpre.sch]
2020-06-07 Update to v1.1.
    Add gerbers and pdfs to plots.
    [thatmicpre.kicad_pcb, thatmicpre.sch]
2020-06-07 Adding schematic pdf to readme
2020-06-07 Add schematic link to readme
2020-06-07 add schematic png
2020-06-07 Add PCB view to readme
2020-06-07 Add pcb photo to readme
2020-06-08 Add .m file to calculate gain resistors. Add comment to schematic
    [thatmicpre.sch]
2020-06-08 Add BOM to plots folder
2021-06-07 Added missing drill files to gerbers
2021-06-07 Added link to diyaudio thread
2022-08-21 Update project files to Kicad 6
    [thatmicpre.kicad_pcb, thatmicpre.kicad_sch, thatmicpre.sch]
2022-08-21 Update 3D models
    [thatmicpre.kicad_pcb]
2022-09-01 Updated picture of PCB
2022-10-10 Add pcb and gerbers for front and backpanels for v1.1
    [thatmicpre-panels.kicad_pcb]
2022-10-10 Update XLR cutout radius and silkscreen placement after testfitting
    [thatmicpre-panels.kicad_pcb]
2022-10-10 Replace csv bom with InteractiveHtmlBom
    Update mfr part nr for some resistors and capacitors,
    to more affordable and easily obtained parts.
    [thatmicpre.kicad_pcb, thatmicpre.kicad_sch, thatmicpre_bom.csv]
2022-10-10 Update readme with panels and html-bom
2022-10-10 Add htmlpreview link to html bom
2022-10-10 Fix html bom link
2023-03-19 Copied v1 design files to rack
    [thatmicpre_v2.kicad_pcb, thatmicpre_v2.kicad_sch]
2023-03-19 Move v1.1 files to v1 folder
    [thatmicpre_v1.kicad_pcb, thatmicpre_v1.kicad_sch]
2023-03-19 Move v1 based plots, docs and pictures to desktop folder
    move panels to desktop
    [thatmicpre-panels.kicad_pcb, thatmicpre_v1.kicad_pcb, thatmicpre_v1.kicad_sch]
2023-03-19 First complete layout of v2
    [thatmicpre_v2.kicad_pcb, thatmicpre_v2.kicad_sch]
2023-03-19 Redo power section layout, add PSU option
    [thatmicpre_v2.kicad_pcb, thatmicpre_v2.kicad_sch]
2023-03-19 Remove PSU option
    [thatmicpre_v2.kicad_pcb, thatmicpre_v2.kicad_sch]
2023-03-19 optimized layout
    added alternative jack and headers
    checked against prints for mech fit
    [thatmicpre_v2.kicad_pcb, thatmicpre_v2.kicad_sch]
2023-03-19 Production version of v2.0 (rack version) with panels
    [thatmicpre-panels.kicad_pcb, thatmicpre_v2.kicad_pcb, thatmicpre_v2.kicad_sch]
2023-03-19 Modified rack version BOM to match assembled prototype
    [thatmicpre-panels.kicad_pcb, thatmicpre_v2.kicad_pcb, thatmicpre_v2.kicad_sch]
2023-03-19 Update readme with 1512 measurements, and v2 schematic
2023-03-19 Fix bom link
2023-10-01 Rack: Correct gain resistor part numbers
    [thatmicpre_v2.kicad_pcb, thatmicpre_v2.kicad_sch]
2024-11-06 Update front-panel pcb to use outline instead of solid circle for holes
    Based on feedback that JLCPCB does not handle solids on edge-cut layer well.
    [thatmicpre-panels.kicad_pcb]
